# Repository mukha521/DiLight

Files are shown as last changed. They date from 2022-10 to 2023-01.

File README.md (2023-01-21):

# DiLight

### Простой светильник с плавным включением и выключением света с датчиком расстояния vl53l0x от ST на базе STM32G030

[Код main()](/firmware/Core/Src/main.c)

[Драйвер vl53l0x](/firmware/Drivers/vl53l0x/)

При долгом удержании пальца на тач-кнопке, включается режим конфигурирования.
Нужно встать на расстоянии, где светильник будет включаться и тапнуть по кнопке.
Затем встать на расстоянии, где светильник будет отключаться и тапнуть по кнопке.
Конфигурация хранится на последней странице флеш-памяти контроллера.

Светильник включается если человек (или что-то другое) приближается на растояние, установленное при конфигурировании и выключается как только человек удаляется на расстояние большее, чем рысстояние выключения.
Тап по кнопке по кругу переключает ражимы работы светильника: Нормальный -> Всегда включен -> Всегда выключен.

[Схема rev.2.0](/kicad/rev.2.0/DiLight_2.0.pdf)

[Интерактивный BOM-лист](/kicad/rev.2.0/bom/)

В устройстве есть защита от переполюсовки птания (подключение с обратной полярностью), но нет защиты от превышения напряжения (12v) и от короткого замыкания по нагрузке. Целью была миниатюризация устройства.

#### Фото реального устройства:

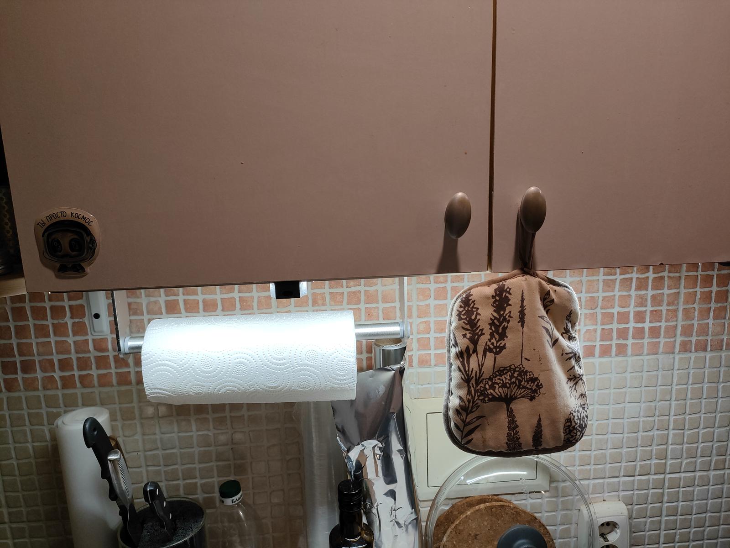
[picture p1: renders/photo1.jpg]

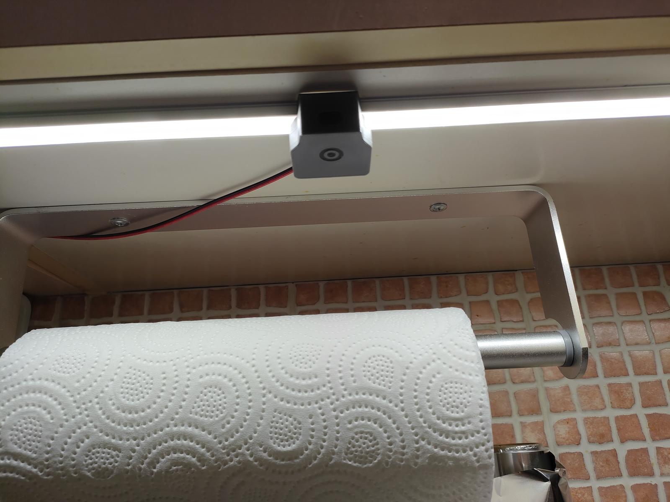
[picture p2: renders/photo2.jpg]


#### Видео с демонстрацией работы:

(кликнуть по изображению - ссылка на YouTube)

YouTube video (http://www.youtube.com/watch?v=1dccDMPywVc)

#### История:

rev.2.0a:
- Исправлена маркировка +/- для терминала LEDs

rev.2.0:
- Уменьшен размер платы
- Использован менее мощный MOSFET в корпусе SOT-23
- Убраны ограничивающие резисторы с разъемов
- Убрана разводка UART на разъем программирования
- Только один терминал для подключения ленты
- Плата с корпусом теперь надевается на профиль для ленты. Не нужно разрезать профиль.

rev.1.1
- винтовой терминал вместо "бочко-разъема" для шнура питания
- MOSFET вместо диода в качестве защиты от обратной полярности питания

#### Рендер платы:
rev.2.0a:
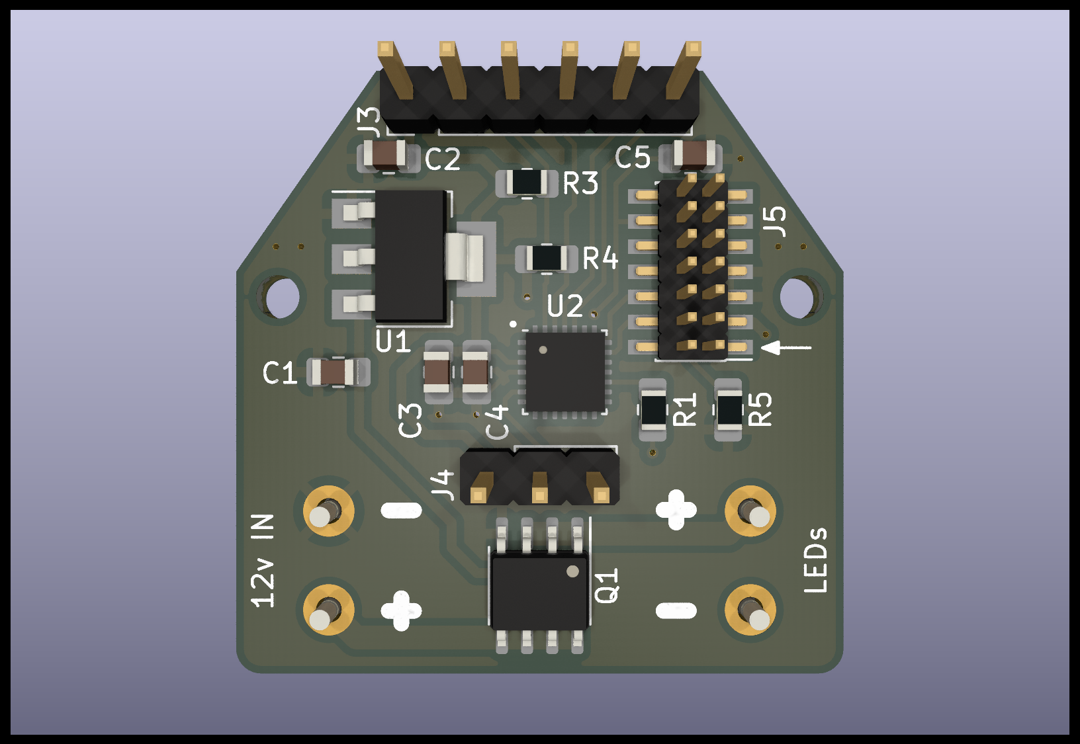
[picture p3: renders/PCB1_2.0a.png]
PCB1 rev.2.0a

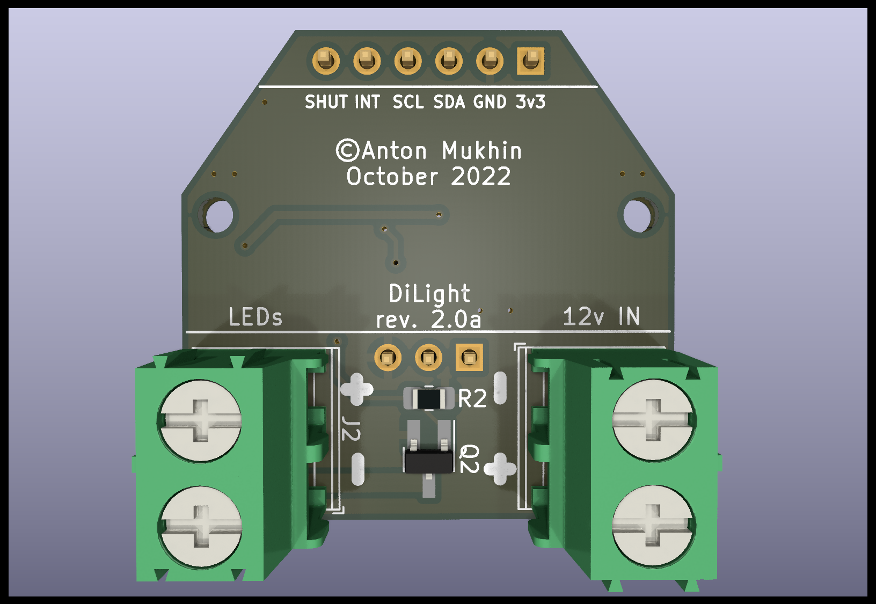
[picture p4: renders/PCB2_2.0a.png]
PCB2 rev.2.0a


rev.2.0:
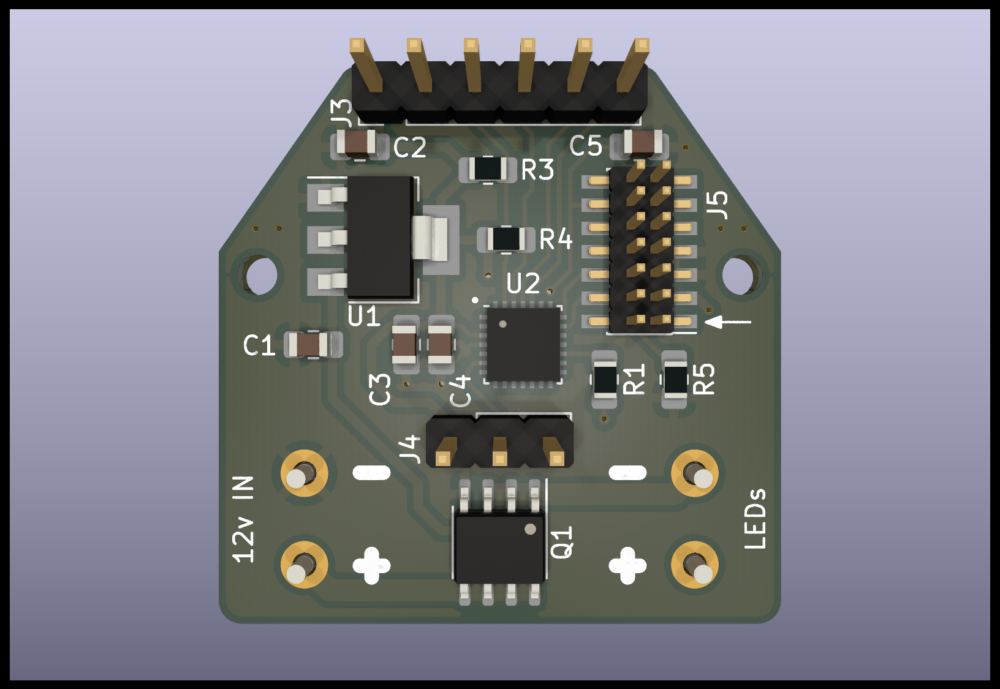
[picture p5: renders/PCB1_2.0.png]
PCB1 rev.2.0

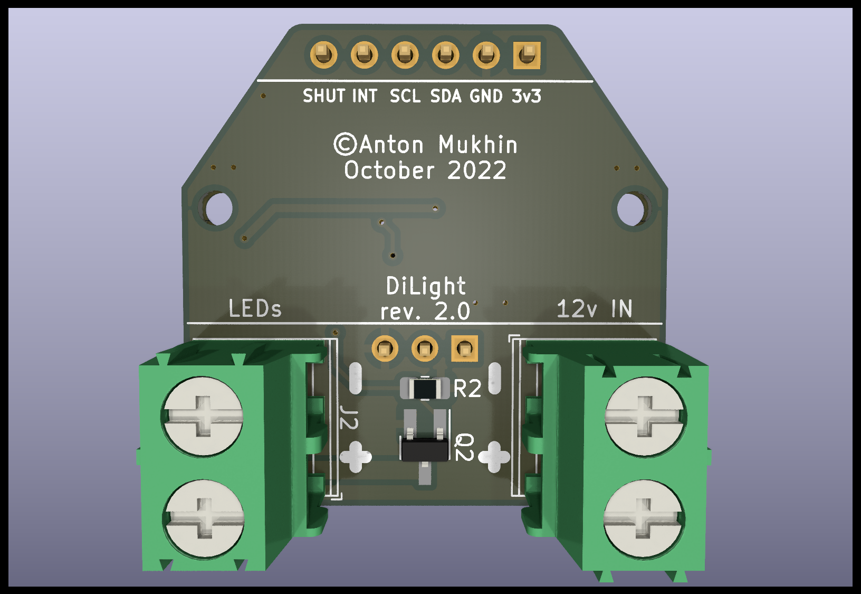
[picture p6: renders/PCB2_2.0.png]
PCB2 rev.2.0


rev.1.1:
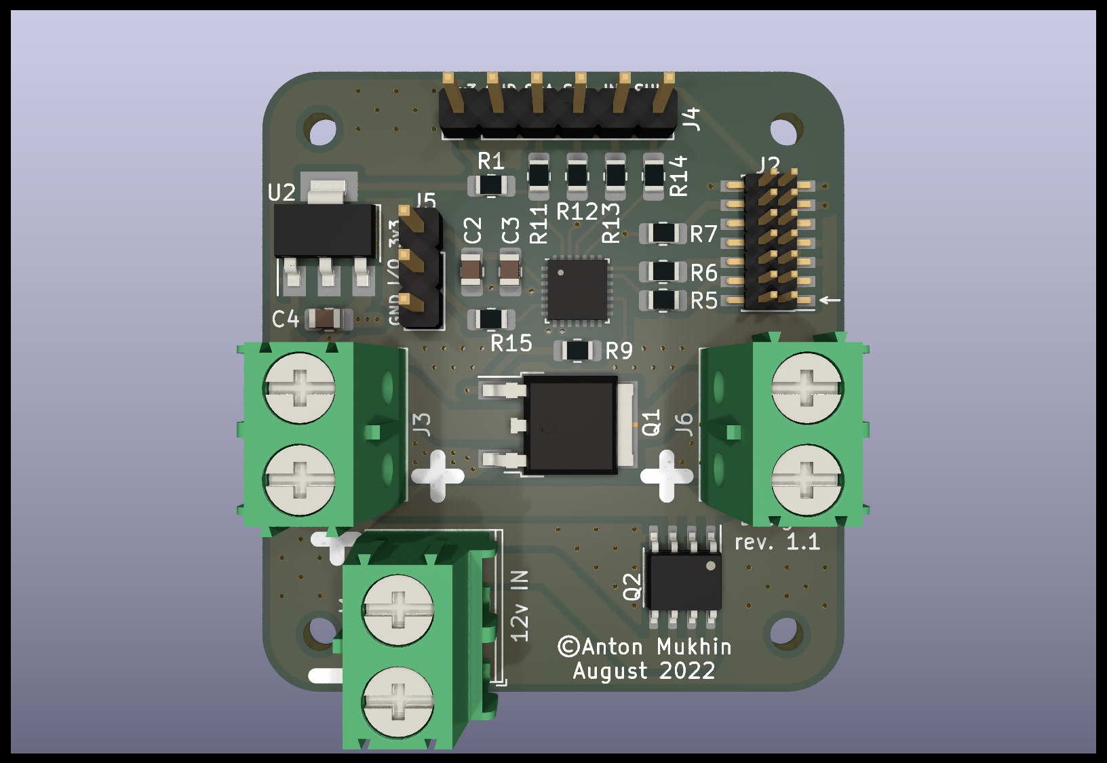
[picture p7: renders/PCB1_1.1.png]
PCB1 rev.1.1

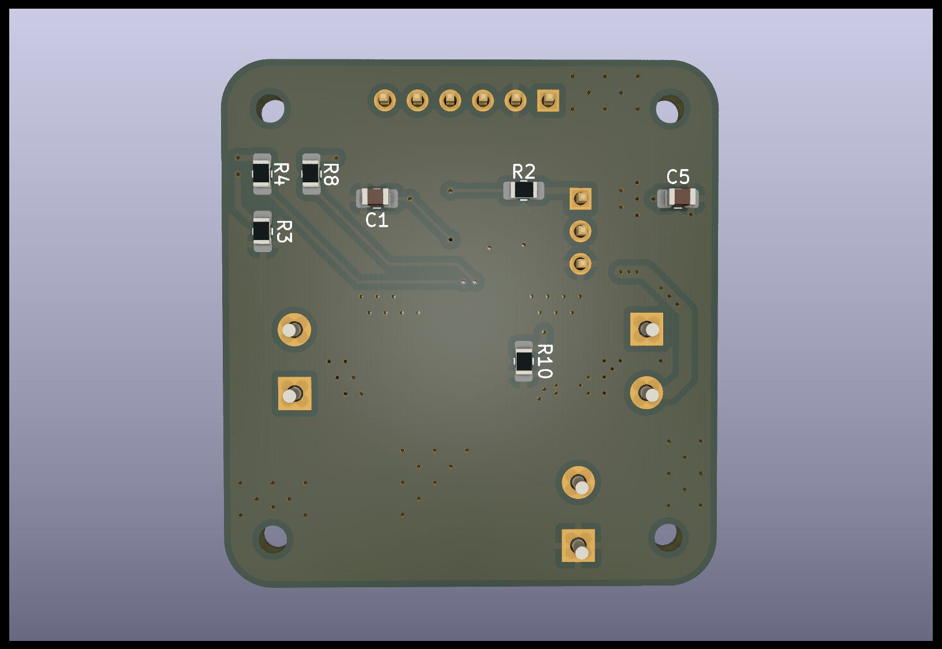
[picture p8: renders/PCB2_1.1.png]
PCB2 rev.1.1


#### Рендер устройства:
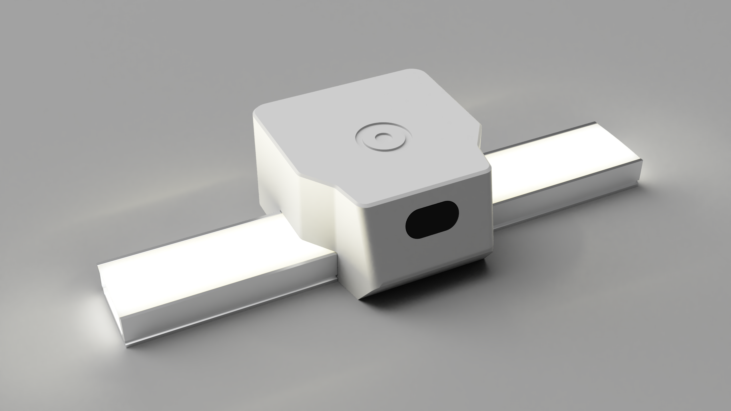
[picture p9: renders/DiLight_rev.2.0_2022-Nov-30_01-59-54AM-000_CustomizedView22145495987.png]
render1

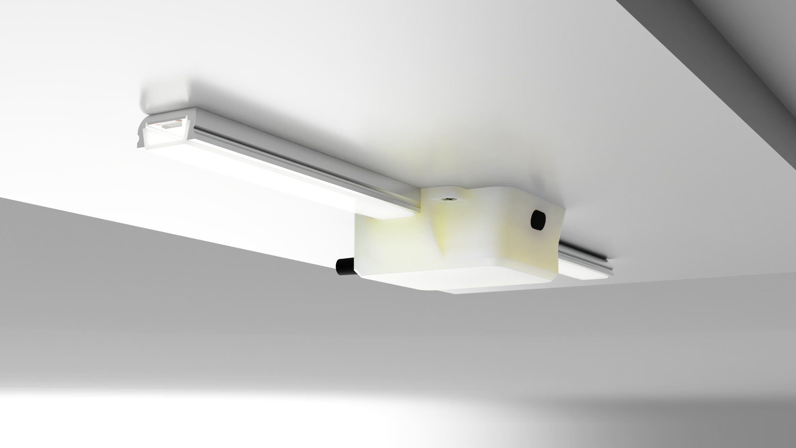
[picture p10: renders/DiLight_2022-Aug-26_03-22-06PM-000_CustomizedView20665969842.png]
render2

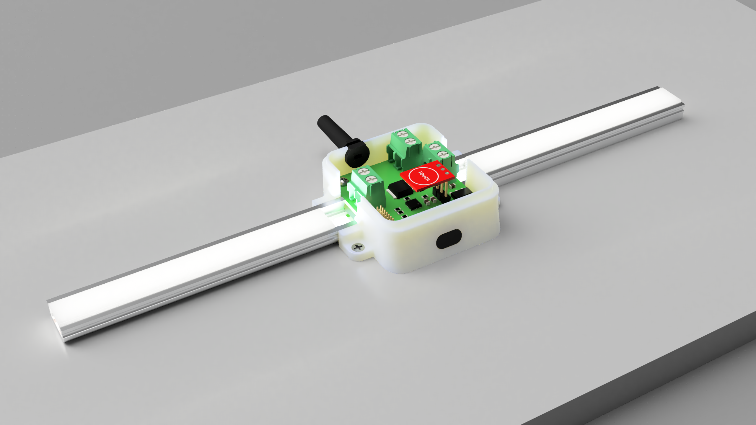
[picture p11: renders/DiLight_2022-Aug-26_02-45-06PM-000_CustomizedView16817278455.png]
render3

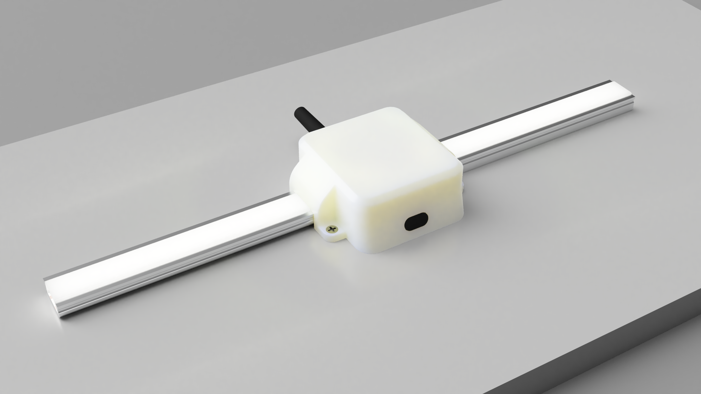
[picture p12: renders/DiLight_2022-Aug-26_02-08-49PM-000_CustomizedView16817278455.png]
render4


#### Промежуточные фото платы (флюс не отмыт :) )
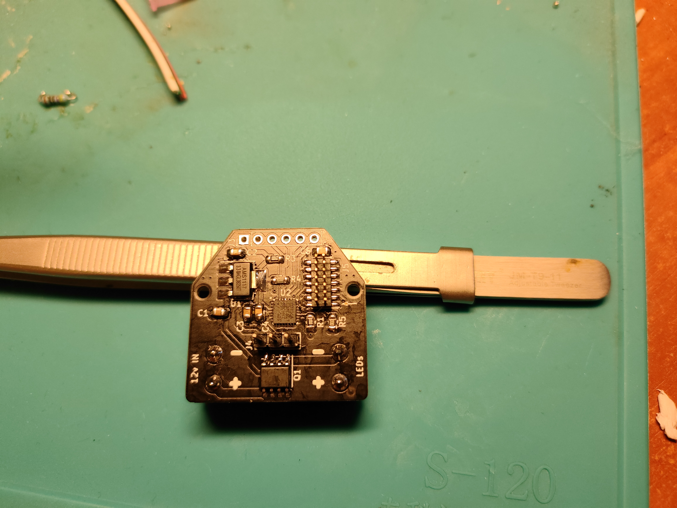
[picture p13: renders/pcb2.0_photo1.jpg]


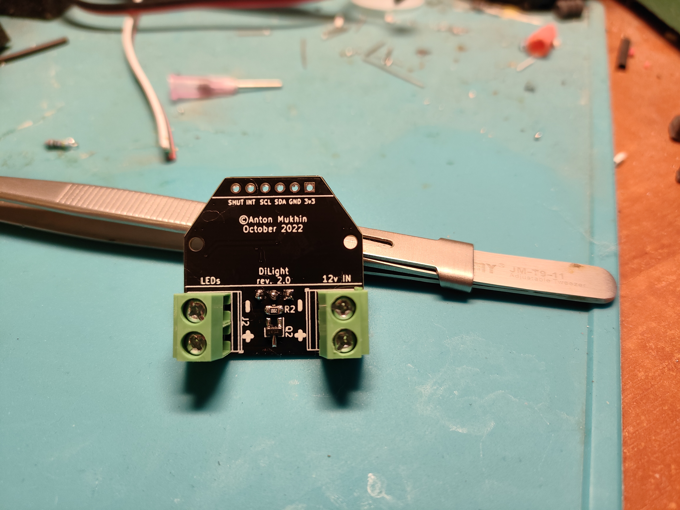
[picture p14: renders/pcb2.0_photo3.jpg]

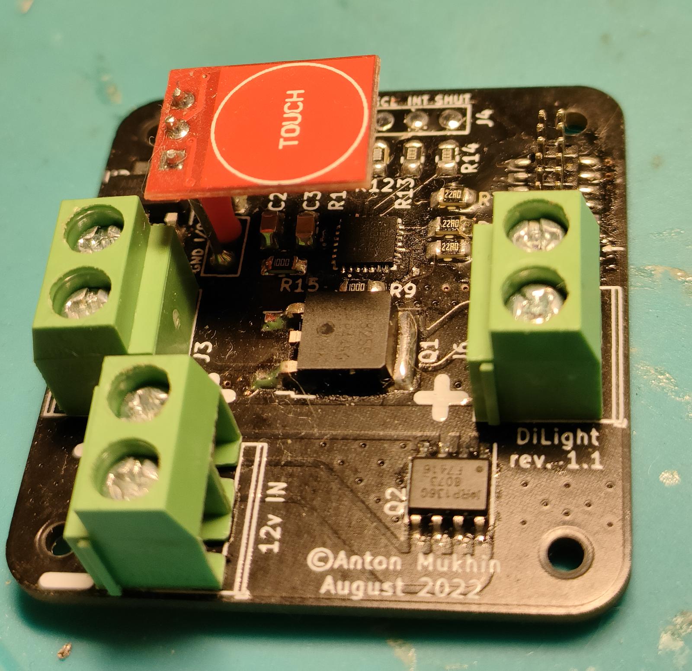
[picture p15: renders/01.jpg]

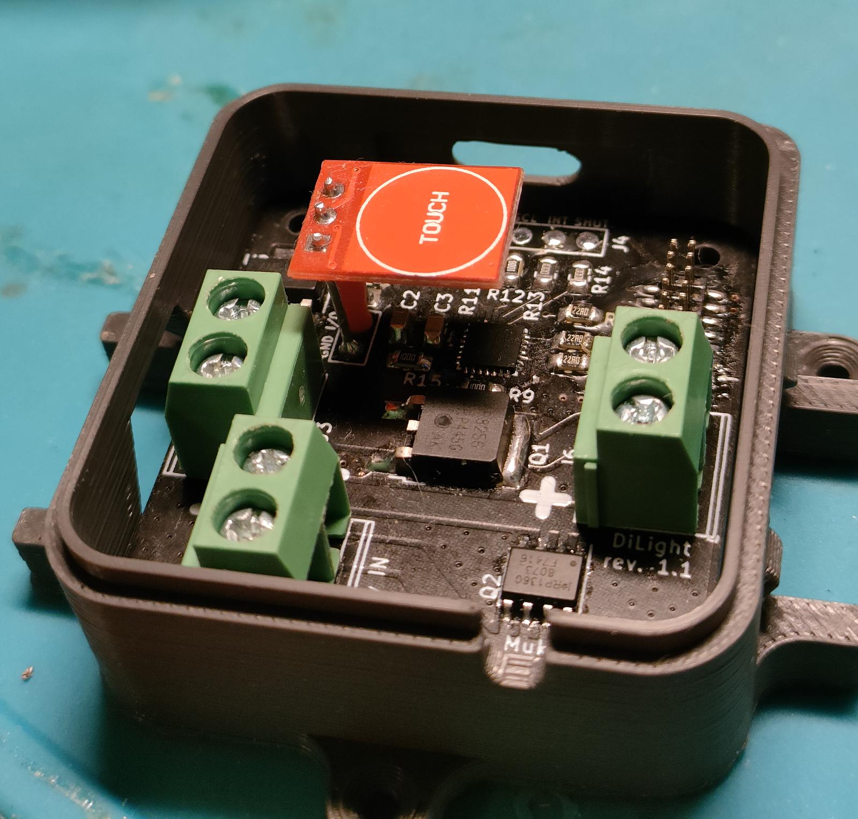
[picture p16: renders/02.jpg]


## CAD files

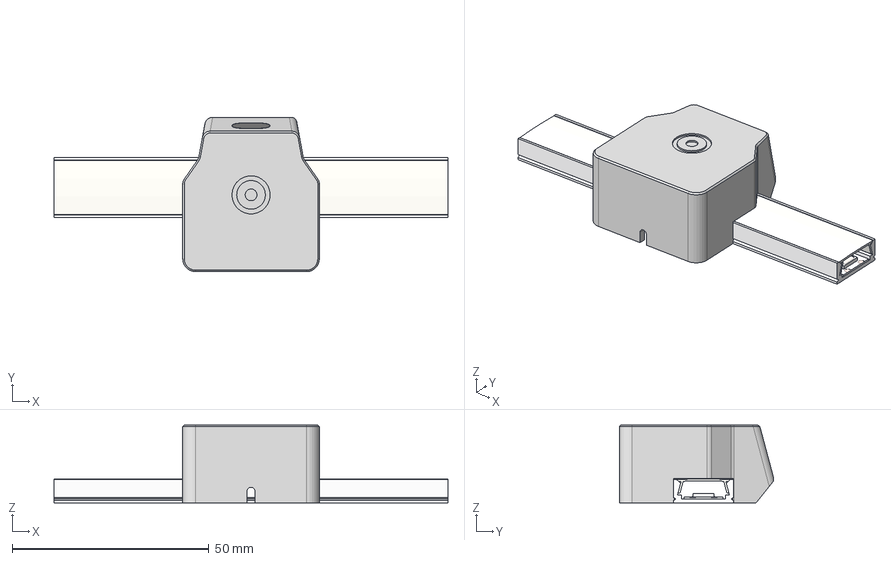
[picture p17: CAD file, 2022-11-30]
STEP/DiLight rev.2.0.step
100.0 x 39.2 x 19.8 mm
strip x 4
LED SMD5054 x 12
resistor x 4
DiLight_2.0 PCB
ScrewTerminalCover x 2
Pin x 4
pan head cross recess screw_iso_ISO 7045 - M2 x 3 - Z - 3N x 4
PCB
Lens
Components
touch button TTP223
M2.2 x 6.5 Rounded Head Screw x 2

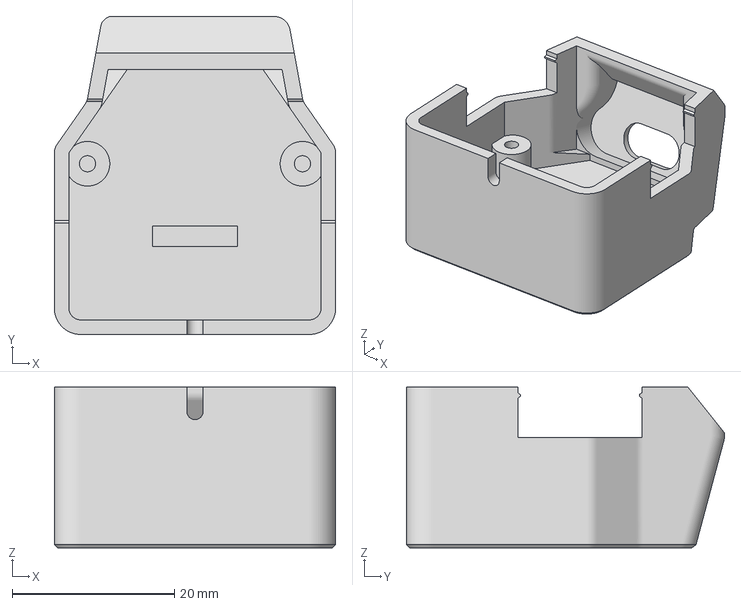
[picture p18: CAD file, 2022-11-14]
STL/Box.3mf
34.7 x 39.2 x 19.8 mm

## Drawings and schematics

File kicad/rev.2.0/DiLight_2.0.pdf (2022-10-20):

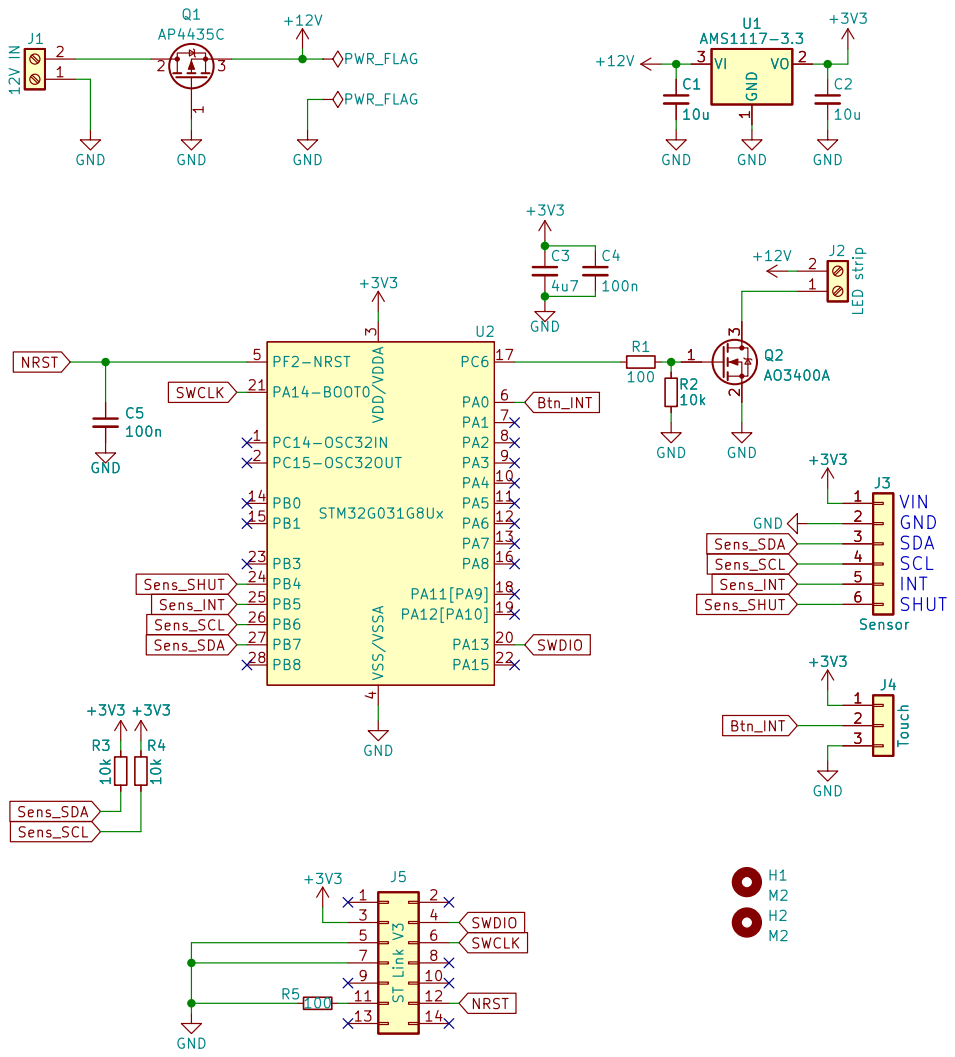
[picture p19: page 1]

File: DiLight_2.0.kicad_sch Sheet: / Anton Mukhin

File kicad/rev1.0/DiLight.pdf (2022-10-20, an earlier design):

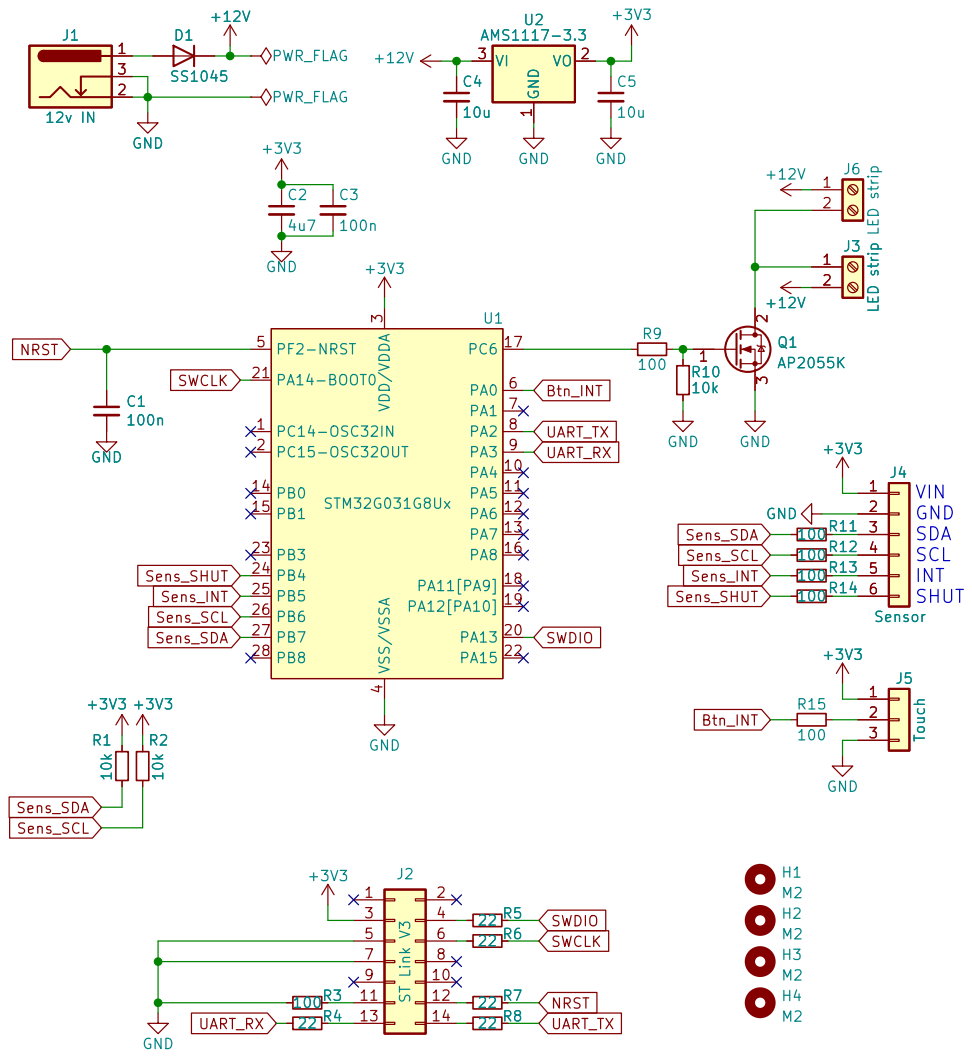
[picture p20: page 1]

File: DiLight.kicad_sch Sheet: / Anton Mukhin

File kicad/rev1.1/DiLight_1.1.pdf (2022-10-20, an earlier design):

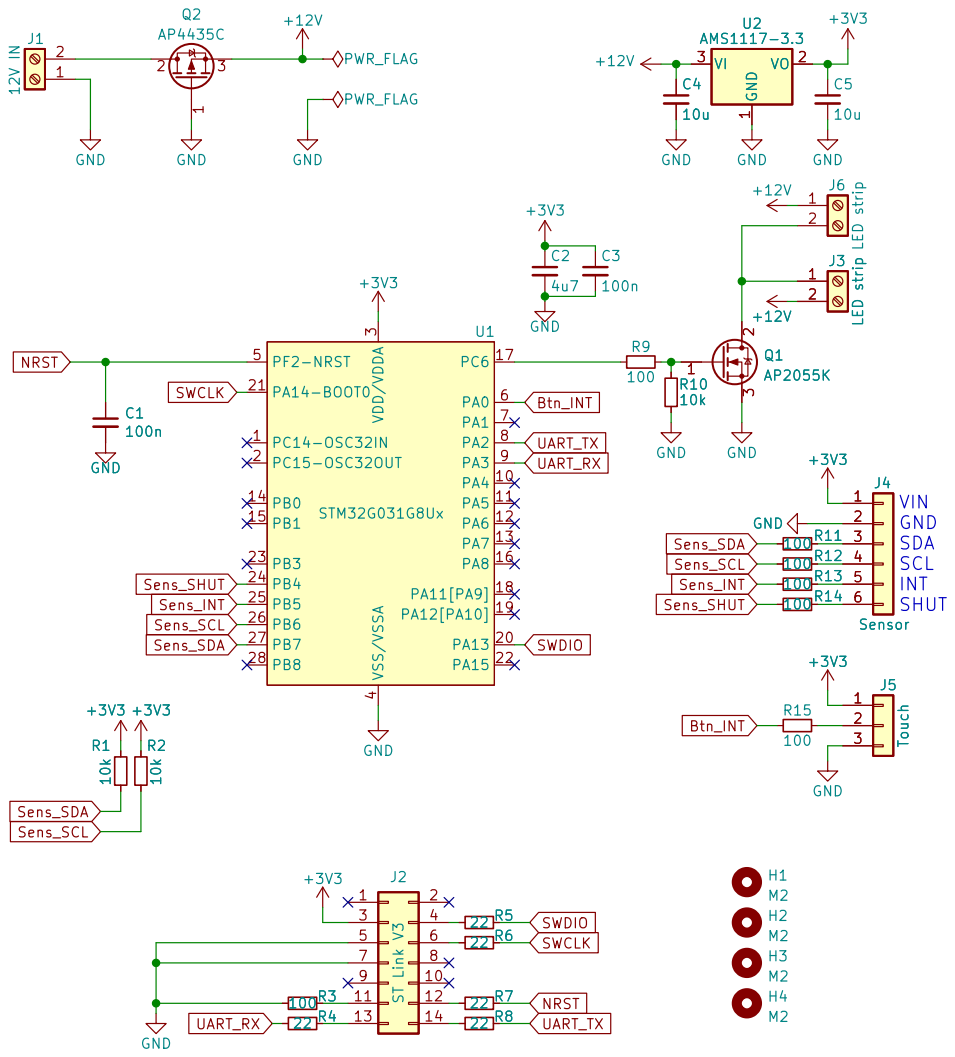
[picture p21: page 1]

File: DiLight_1.1.kicad_sch Sheet: / Anton Mukhin

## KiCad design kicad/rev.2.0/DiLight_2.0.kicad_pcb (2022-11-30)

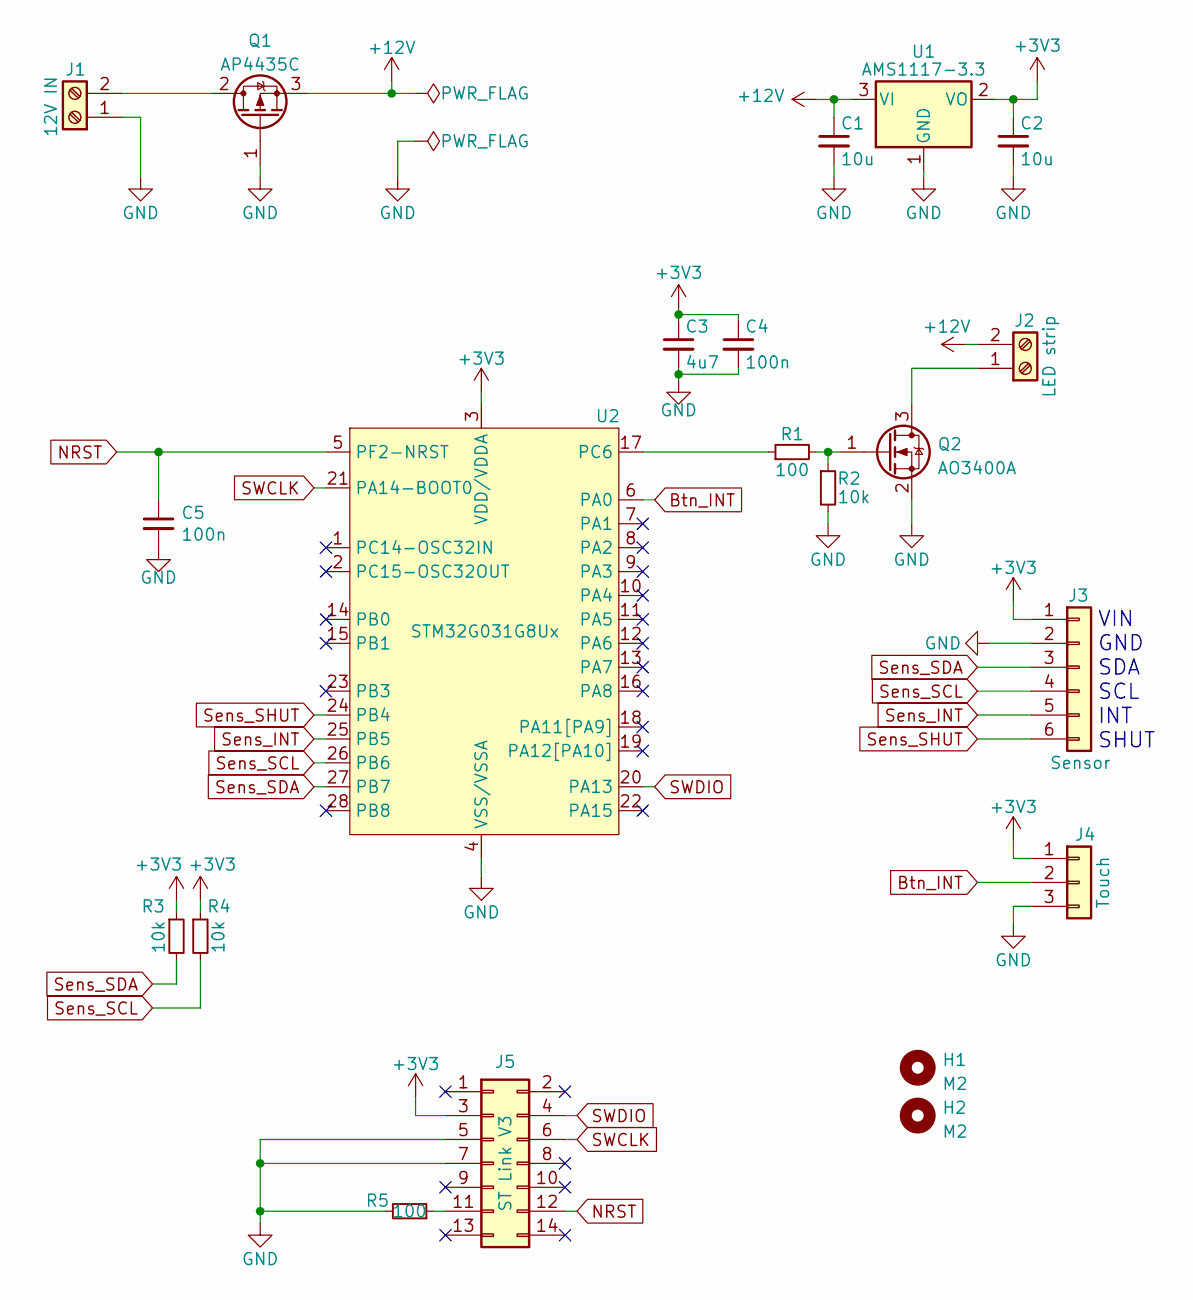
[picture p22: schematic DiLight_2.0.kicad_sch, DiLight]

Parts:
C1, C2: 10u; C_0805_2012Metric_Pad1.18x1.45mm_HandSolder
C3: 4u7; C_0805_2012Metric_Pad1.18x1.45mm_HandSolder
C4, C5: 100n; C_0805_2012Metric_Pad1.18x1.45mm_HandSolder
H1, H2: M2; MountingHole_2.2mm_M2_DIN965
J1: 12V IN; TerminalBlock_Phoenix_PT-1,5-2-5.0-H_1x02_P5.00mm_Horizontal
J2: LED strip; TerminalBlock_Phoenix_PT-1,5-2-5.0-H_1x02_P5.00mm_Horizontal
J3: Sensor; PinHeader_1x06_P2.54mm_Vertical
J4: Touch; PinHeader_1x03_P2.54mm_Vertical
J5: ST Link V3; PinHeader_2x07_P1.27mm_Vertical_SMD
Q1: AP4435C; SOP-8_PMOS_GDS
Q2: AO3400A; SOT-23_Handsoldering
R1, R5: 100; R_0805_2012Metric_Pad1.20x1.40mm_HandSolder
R2, R3, R4: 10k; R_0805_2012Metric_Pad1.20x1.40mm_HandSolder
U1: AMS1117-3.3; SOT-223-3_TabPin2
U2: STM32G031G8Ux; QFN-28_4x4mm_P0.5mm

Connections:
+3V3: C2.1, C3.1, C4.1, J3.1, J4.1, J5.3, R3.1, R4.1, U1.2 (VO), U2.3 (VDD/VDDA)
+12V: C1.1, J2.2, Q1.3 (S), U1.3 (VI)
Btn_INT: J4.2, U2.6 (PA0)
GND: C1.2, C2.2, C3.2, C4.2, C5.2, J1.1, J3.2, J4.3, J5.5, J5.7, Q1.1 (G), Q2.2 (S), R2.2, R5.2, U1.1 (GND), U2.4 (VSS/VSSA)
NRST: C5.1, J5.12, U2.5 (PF2-NRST)
unnamed: J1.2, Q1.2 (D)
unnamed: J2.1, Q2.3 (D)
unnamed: J5.11, R5.1
unnamed: Q2.1 (G), R1.2, R2.1
unnamed: R1.1, U2.17 (PC6)
SWCLK: J5.6, U2.21 (PA14-BOOT0)
SWDIO: J5.4, U2.20 (PA13)
Sens_INT: J3.5, U2.25 (PB5)
Sens_SCL: J3.4, R4.2, U2.26 (PB6)
Sens_SDA: J3.3, R3.2, U2.27 (PB7)
Sens_SHUT: J3.6, U2.24 (PB4)

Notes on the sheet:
VIN GND SDA SCL INT SHUT

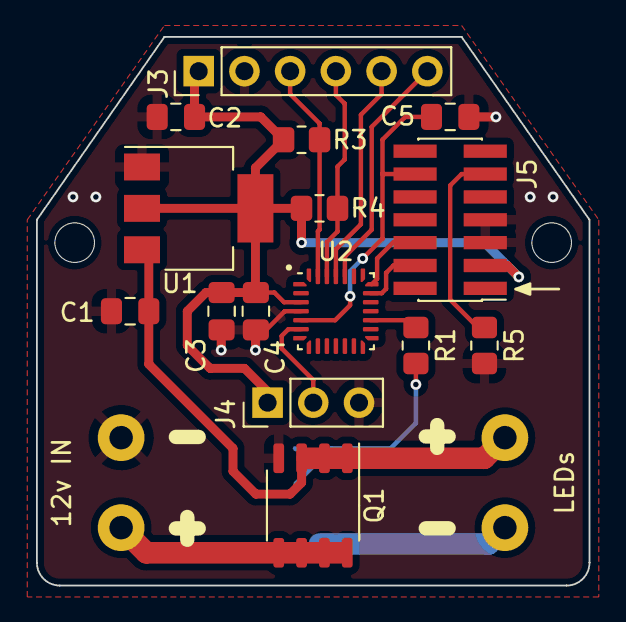
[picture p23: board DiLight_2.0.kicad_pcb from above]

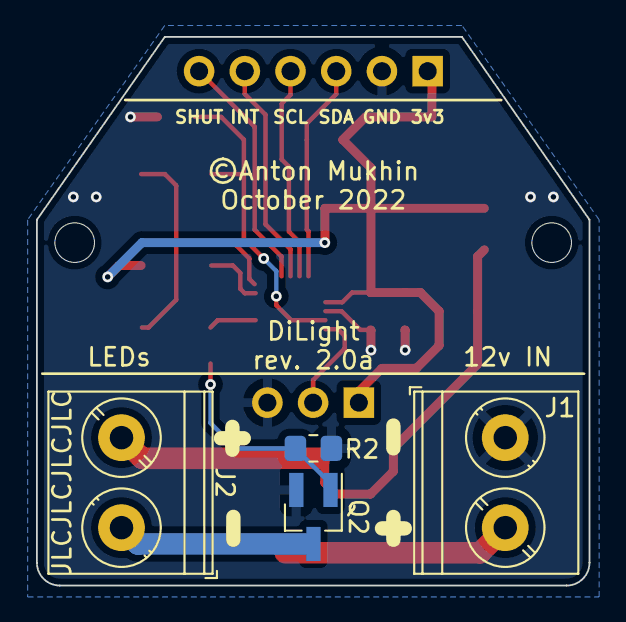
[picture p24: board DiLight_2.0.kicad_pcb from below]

Board: 2 copper layers, 30.7 x 30.5 mm, 21 parts (4 on the bottom side), 16 nets.

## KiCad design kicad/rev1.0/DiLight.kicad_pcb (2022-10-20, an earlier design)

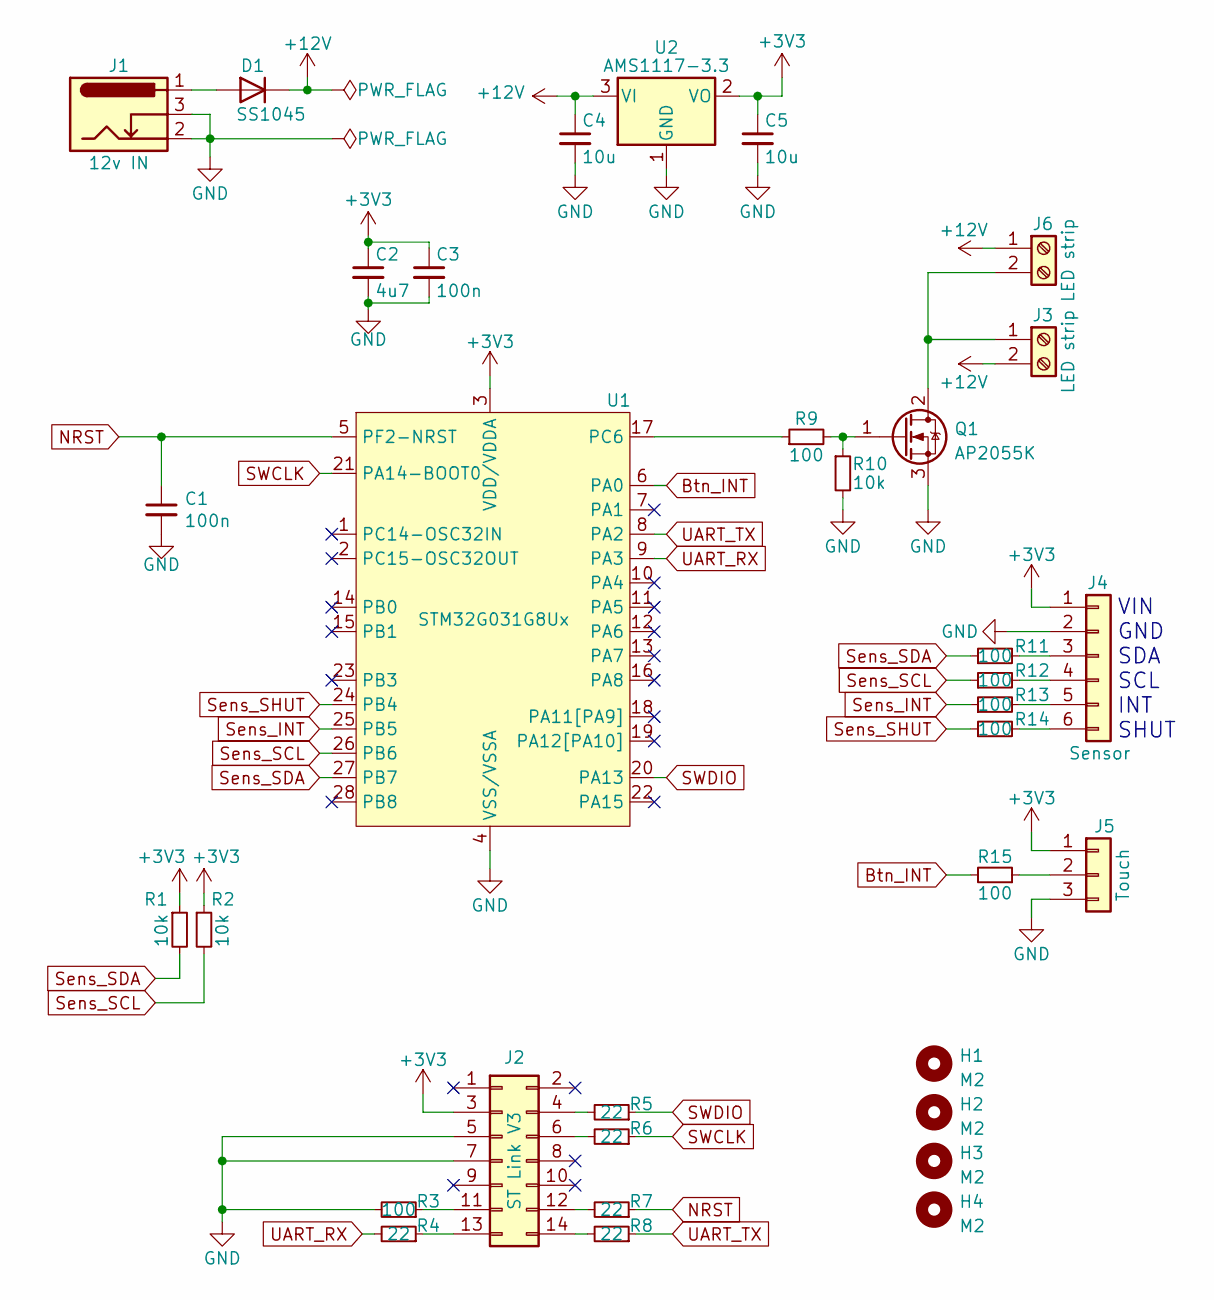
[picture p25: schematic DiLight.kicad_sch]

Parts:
C1, C3: 100n; C_0805_2012Metric_Pad1.18x1.45mm_HandSolder
C2: 4u7; C_0805_2012Metric_Pad1.18x1.45mm_HandSolder
C4, C5: 10u; C_0805_2012Metric_Pad1.18x1.45mm_HandSolder
D1: SS1045; D_SMB-SMC_Universal_Handsoldering
H1, H2, H3, H4: M2; MountingHole_2.2mm_M2_DIN965
J1: 12v IN; BarrelJack_Horizontal
J2: ST Link V3; PinHeader_2x07_P1.27mm_Vertical_SMD
J3, J6: LED strip; TerminalBlock_Phoenix_PT-1,5-2-5.0-H_1x02_P5.00mm_Horizontal
J4: Sensor; PinHeader_1x06_P2.54mm_Vertical
J5: Touch; PinHeader_1x03_P2.54mm_Vertical
Q1: AP2055K; TO-252-2
R1, R2, R10: 10k; R_0805_2012Metric_Pad1.20x1.40mm_HandSolder
R3, R9, R11, R12, R13, R14, R15: 100; R_0805_2012Metric_Pad1.20x1.40mm_HandSolder
R4, R5, R6, R7, R8: 22; R_0805_2012Metric_Pad1.20x1.40mm_HandSolder
U1: STM32G031G8Ux; QFN-28_4x4mm_P0.5mm
U2: AMS1117-3.3; SOT-223-3_TabPin2

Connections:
+3V3: C2.1, C3.1, C5.1, J2.3, J4.1, J5.1, R1.1, R2.1, U1.3 (VDD/VDDA), U2.2 (VO)
+12V: C4.1, D1.1 (K), J3.2, J6.1, U2.3 (VI)
Btn_INT: R15.2, U1.6 (PA0)
GND: C1.2, C2.2, C3.2, C4.2, C5.2, J1.2, J1.3, J2.5, J2.7, J4.2, J5.3, Q1.3 (S), R3.2, R10.2, U1.4 (VSS/VSSA), U2.1 (GND)
NRST: C1.1, R7.1, U1.5 (PF2-NRST)
unnamed: D1.2 (A), J1.1
unnamed: J2.4, R5.2
unnamed: J2.6, R6.2
unnamed: J2.11, R3.1
unnamed: J2.12, R7.2
unnamed: J2.13, R4.1
unnamed: J2.14, R8.2
unnamed: J5.2, R15.1
unnamed: J3.1, J6.2, Q1.2 (D)
unnamed: R9.1, U1.17 (PC6)
unnamed: Q1.1 (G), R9.2, R10.1
unnamed: J4.3, R11.2
unnamed: J4.4, R12.2
unnamed: J4.5, R13.2
unnamed: J4.6, R14.2
SWCLK: R6.1, U1.21 (PA14-BOOT0)
SWDIO: R5.1, U1.20 (PA13)
Sens_INT: R13.1, U1.25 (PB5)
Sens_SCL: R2.2, R12.1, U1.26 (PB6)
Sens_SDA: R1.2, R11.1, U1.27 (PB7)
Sens_SHUT: R14.1, U1.24 (PB4)
UART_RX: R4.2, U1.9 (PA3)
UART_TX: R8.1, U1.8 (PA2)

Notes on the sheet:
VIN GND SDA SCL INT SHUT

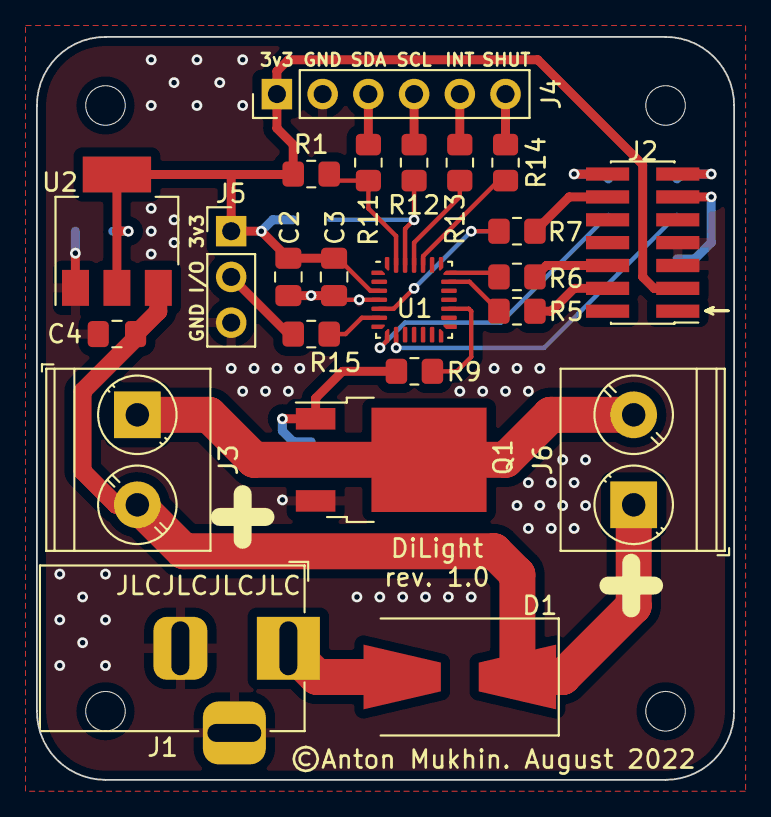
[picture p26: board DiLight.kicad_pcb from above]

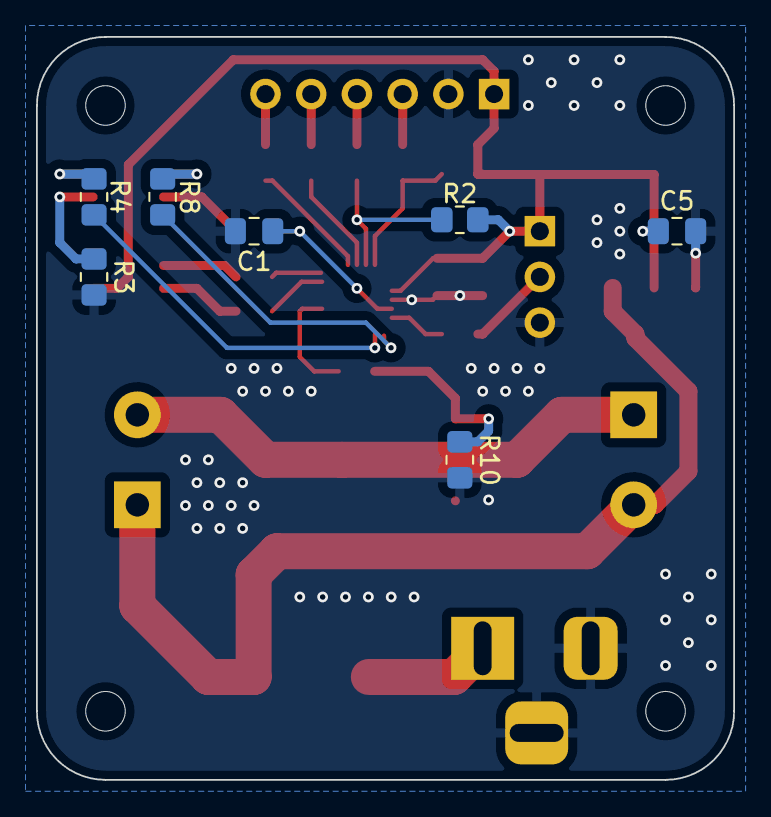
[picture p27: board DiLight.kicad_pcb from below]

Board: 2 copper layers, 38.7 x 41.3 mm, 34 parts (7 on the bottom side), 28 nets.

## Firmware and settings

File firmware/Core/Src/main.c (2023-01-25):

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
/* Includes ------------------------------------------------------------------*/
#include "main.h"

/* USER CODE BEGIN Includes */
#include "string.h"
#include "stdio.h"
#include "VL53L0X.h"
/* USER CODE END Includes */

/* USER CODE BEGIN PTD */

//Configuration structure to keep in last (31) page of FLASH
typedef struct {
	uint32_t token;			//CONF_TOKEN
	uint16_t dist_on;		//distance to turn on lights
	uint16_t dist_off;	//distance to turn off lights
} conf_t;
struct FLASH_sector {
	uint8_t  data[8];		//Config data
	uint32_t counter;		//Configuration write counter
	uint32_t checksum;	//Checksum to verify saved data
};

typedef enum DLMode_t_enum {
	DL_normal = 0,
	DL_manual_on,
	DL_manual_off,
	DL_need_config,
	DL_config_waiting,
	DL_config_accepted,
	DL_error
} DLMode_t;

/* USER CODE END PTD */

/* USER CODE BEGIN PD */

#define DEFAULT_DIST_ON		500											//Default lights on distance
#define DEFAULT_DIST_OFF	1000										//Default lights off distance
#define MIN_DIST_GAP			100											//Min gap between on and off distances
#define MAX_DIST					1400										//Max distance that could be reliably measured by the sensor

#define CONF_TOKEN				0x000A0200							//32bit token to check the configuration struct in the FLASH (000A - DiLight; rev2.0)
#define CONF_FLASH_ADDR 	((uint32_t)0x0800F800)	//FLASH address of the page to save configuration to
#define CONF_FLASH_PAGE 	31											//FLASH page number (from 0 to PgCount-1)

/* USER CODE END PD */

CRC_HandleTypeDef hcrc;

I2C_HandleTypeDef hi2c1;

TIM_HandleTypeDef htim3;
TIM_HandleTypeDef htim16;
TIM_HandleTypeDef htim17;

/* USER CODE BEGIN PV */

//volatile const uint8_t config_flash[1024 * 2] __attribute__((__section__(".conf_data")));

union FLASH_conf {
	  conf_t config;
	  struct FLASH_sector sector;
	  uint32_t data32[4];
	  uint64_t data64[2];
} configuration;
#define FLASH_CONF_SIZE 16

uint8_t  TOF_Ready = 0;							// Flag to ignore TOF IRQ before it is initialized
uint8_t  curLightLevel = 0;					// Current light level (0-99)
uint16_t curDist = 0;								// Current measured distance in mm
uint16_t btn_ticks;									// How many ticks the button is pressed (1 tick = 100ms)
int8_t   dLevel = 1;								// Direction of fade: -1 for fade out; 1 for fade in;
DLMode_t DLmode = DL_normal;				// Global mode: DL_normal, DL_manual_on, DL_manual_off, DL_need_config, DL_config_waiting, DL_config_accepted, DL_error
DLMode_t prev_mode = DL_normal;			// To hold the mode during temporary mode switches
uint8_t  modeSwitch = 0;						// Flag to switch the mode after the button tap

/* USER CODE END PV */

void SystemClock_Config(void);
static void MX_GPIO_Init(void);
static void MX_I2C1_Init(void);
static void MX_TIM3_Init(void);
static void MX_TIM17_Init(void);
static void MX_CRC_Init(void);
static void MX_TIM16_Init(void);
/* USER CODE BEGIN PFP */

volatile void loadConfig(void);							// Load configuration from the FLASH memory
volatile void saveConfig(void);							// Save configuration to the FLASH memory
volatile void setLightLevel(uint8_t level);	// Set the lights level (brightness) 0 - 99
void fastBlink(uint8_t count);							// Fast blink LEDs `count` times
void configure(void);												// Range configuration procedure (set on and off ranges)


/* USER CODE END PFP */

/* USER CODE BEGIN 0 */

//load configuration from FLASH
volatile void loadConfig(void) {
	uint32_t l_Address = CONF_FLASH_ADDR;
	uint32_t l_Index = 0;

	//Reading from FLASH
	while (l_Address < (CONF_FLASH_ADDR + FLASH_CONF_SIZE)) {
	  configuration.data64[l_Index] = *(__IO uint64_t *)l_Address;
	  l_Index += 1;
	  l_Address += 8;
	}

	//Calculate a hash from the configuration
	if (HAL_CRC_Calculate(&hcrc, configuration.data32, 2) != configuration.sector.checksum
			|| configuration.config.token != CONF_TOKEN) {
		//First start or configuration is corrupted
		saveConfig();  //Save dafault config
	} // else successfully read the configuration

}

//save configuration to FLASH
volatile void saveConfig(void) {
  static FLASH_EraseInitTypeDef EraseInitStruct;
  uint32_t l_Address = CONF_FLASH_ADDR;
  uint32_t l_Index = 0;
  uint32_t l_Error = 0;

  //We need it to erase a page
  EraseInitStruct.TypeErase = FLASH_TYPEERASE_PAGES;
  EraseInitStruct.Page      = CONF_FLASH_PAGE;
  EraseInitStruct.NbPages   = 1;

  if (configuration.config.token != CONF_TOKEN) {
	  //first start
	  //Nullify the struct
	  memset(configuration.data64, 0, sizeof(configuration.data64));
	  //set default values
	  configuration.config.token = CONF_TOKEN;
	  configuration.config.dist_on = DEFAULT_DIST_ON;
	  configuration.config.dist_off = DEFAULT_DIST_OFF;

	  configuration.sector.counter = 0;
  }

  // Check if the distances are good.
  // (1 max distance is respected. 2 min gap between on and off distances is respected)
  if (configuration.config.dist_off > MAX_DIST) configuration.config.dist_off = MAX_DIST;
  if (configuration.config.dist_off < MIN_DIST_GAP) configuration.config.dist_off = MIN_DIST_GAP;
  if (configuration.config.dist_on > configuration.config.dist_off - MIN_DIST_GAP) configuration.config.dist_on = configuration.config.dist_off - MIN_DIST_GAP;
  configuration.sector.counter += 1;
  configuration.sector.checksum = HAL_CRC_Calculate(&hcrc, configuration.data32, 2);

  HAL_FLASH_Unlock();															//Unlock the FLASH
  HAL_FLASHEx_Erase(&EraseInitStruct, &l_Error);	//Erase the page

  // Programming the config

  while (l_Address < (CONF_FLASH_ADDR + FLASH_CONF_SIZE)) {
	  if  (HAL_FLASH_Program(FLASH_TYPEPROGRAM_DOUBLEWORD, l_Address, configuration.data64[l_Index]) == HAL_OK) {
		  l_Index += 1;
		  l_Address += 8;
	  }
  }
  HAL_FLASH_Lock();
  HAL_Delay(50);
}

// Fast blink LEDs `count` times
void fastBlink(uint8_t count) {
	uint8_t i, pll;

	pll = curLightLevel;
	setLightLevel(0);
	for (i = 0; i < count; i++) {
		setLightLevel(99);
		HAL_Delay(80);
		setLightLevel(0);
		HAL_Delay(80);
	}
	setLightLevel(pll);
}

// Range configuration procedure (set on and off ranges)
void configure(void) {
	DLmode = DL_config_waiting;

	//Fast blink 5 times
	fastBlink(5);

	//Configure ON distance
	while (DLmode == DL_config_waiting) {
		HAL_Delay(250);
		if (curDist > MAX_DIST - MIN_DIST_GAP) setLightLevel(0);
		// (x - in_min) * (out_max - out_min) / (in_max - in_min) + out_min
		// (x - 0) * (50 - 0) / (1400 - 0) + 0
		// x * 50 / 1400
		// (99 - curDist * 99 / 2000)     //old version
		else setLightLevel((uint8_t)(50 - curDist * 50 / (MAX_DIST - MIN_DIST_GAP)));		// Map light level to the distance
	}
	configuration.config.dist_on = curDist;			// this will be checked during config save

	//Fast blink 2 times
	DLmode = DL_config_waiting;
	fastBlink(2);

	//Configure OFF distance
	while (DLmode == DL_config_waiting) {
		HAL_Delay(250);
		if (curDist > MAX_DIST) setLightLevel(0);
		else setLightLevel((uint8_t)(50 - curDist * 50 / MAX_DIST));		// Map light level to the distance
	}
	configuration.config.dist_off = curDist;		// this will be checked during config save

  saveConfig();

	//Fast blink 5 times
  fastBlink(5);
}

/* USER CODE END 0 */

/**
  * @brief  The application entry point.
  * @retval int
  */
int main(void)
{
  /* MCU Configuration--------------------------------------------------------*/

  /* Reset of all peripherals, Initializes the Flash interface and the Systick. */
  HAL_Init();

  /* Configure the system clock */
  SystemClock_Config();

  /* Initialize all configured peripherals */
  MX_GPIO_Init();
  MX_I2C1_Init();
  MX_TIM3_Init();
  MX_TIM17_Init();
  MX_CRC_Init();
  MX_TIM16_Init();
  /* USER CODE BEGIN 2 */

  // TIM3  - PWM timer
  // TIM16 - ticks timer (10Hz - 100ms)
  // TIM17 - timer for light fading

  loadConfig();

  // Set IO timeout for range sensor
  setTimeout(250);

  TOF_Ready = initVL53L0X(1);
  if (TOF_Ready) {
		// lower the return signal rate limit (default is 0.25 MCPS)
		// setSignalRateLimit(0.1);
		// increase laser pulse periods (defaults are 14 and 10 PCLKs)
		// setVcselPulsePeriod(VcselPeriodPreRange, 18);
		// setVcselPulsePeriod(VcselPeriodFinalRange, 14);
		setMeasurementTimingBudget( 500 * 1000UL );		// integrate over 500 ms per measurement

		// Start measurements every second
		startContinuous(1000);
  }
  HAL_TIM_PWM_Start(&htim3, TIM_CHANNEL_1);

  // Fast-blink 10 times to indicate range sensor error
	if (!TOF_Ready) {
		fastBlink(10);
	}


  /* USER CODE END 2 */

  /* Infinite loop */
  /* USER CODE BEGIN WHILE */
  while (1)
  {
  	if (DLmode == DL_need_config) {
  		configure();
  		DLmode = prev_mode;
  	}

  	// Check if the button was tapped and we should switch the mode
  	if (modeSwitch) {
  		modeSwitch = 0;
  		switch (DLmode) {
				case DL_normal:
					DLmode = DL_manual_on;
					fastBlink(1);
					dLevel = 2;
					HAL_TIM_Base_Start_IT(&htim17);
					break;
				case DL_manual_on:
					DLmode = DL_manual_off;
					fastBlink(1);
					dLevel = -1;
					HAL_TIM_Base_Start_IT(&htim17);
					break;
				case DL_manual_off:
					DLmode = DL_normal;
					fastBlink(2);
					break;
				default:
					break;
			}
		}

  	HAL_Delay(50);
    /* USER CODE END WHILE */

    /* USER CODE BEGIN 3 */
  }
  /* USER CODE END 3 */
}

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
/* USER CODE BEGIN 4 */

volatile void setLightLevel(uint8_t level) {
	if (level > 99) level = 99;
	curLightLevel = level;

	TIM3->CCR1 = curLightLevel;
}

void HAL_GPIO_EXTI_Rising_Callback(uint16_t GPIO_Pin) {
	// Start counting "ticks" when the sense-button is pressed
	if (GPIO_Pin == Btn_INT_Pin) {
		btn_ticks = 0;
		HAL_TIM_Base_Start_IT(&htim16);
	}
}


void HAL_GPIO_EXTI_Falling_Callback(uint16_t GPIO_Pin) {
	uint16_t dist;

	// Range sensor interrupt (measurement is done)
	if (TOF_Ready && GPIO_Pin == Sens_INT_Pin) {
		dist = readRangeContinuousMillimeters(0);
		if (dist < MAX_DIST)	curDist = dist;
		else curDist = MAX_DIST;
		if (DLmode == DL_normal) {
			if (curDist <= configuration.config.dist_on && curLightLevel < 90) {
				//Turn on the lights
				dLevel = 2;
				HAL_TIM_Base_Start_IT(&htim17);
			}
			if (curDist >= configuration.config.dist_off && curLightLevel == 99) {
				//Turn off the lights
				dLevel = -1;
				HAL_TIM_Base_Start_IT(&htim17);
			}
		}
	}

	// The sense-button is released
	if (GPIO_Pin == Btn_INT_Pin) {
		HAL_TIM_Base_Stop_IT(&htim16);
		if (btn_ticks < 60) {
			// Button was not held for more than 6 seconds
			if (DLmode == DL_config_waiting) {
				DLmode = DL_config_accepted;
			} else {
				modeSwitch = 1;
			}
		}
	}
}

void HAL_TIM_PeriodElapsedCallback(TIM_HandleTypeDef *htim) {
	if(htim->Instance == TIM16) { //check if the interrupt comes from TIM16   // TIM16 - ticks timer (10Hz - 100ms)
		if (btn_ticks < 60) {
			btn_ticks++;
		} else {
			// the button is held for more than 6 seconds
			HAL_TIM_Base_Stop_IT(&htim16);
			prev_mode = DLmode;
			DLmode = DL_need_config;
		}
	}

	// Fade-in / fade-out animation
	if(htim->Instance == TIM17) { //check if the interrupt comes from TIM17  // TIM17 - timer for light fading
		if ((curLightLevel >= 99 && dLevel > 0) || (curLightLevel == 0 && dLevel < 0)) {
			HAL_TIM_Base_Stop_IT(&htim17);
		} else {
			curLightLevel += dLevel;
			setLightLevel(curLightLevel);
		}
	}
}

/* USER CODE END 4 */
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


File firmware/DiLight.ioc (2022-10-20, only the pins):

Mcu.UserName=STM32G031G8Ux
PA0.GPIO_Label=Btn_INT
PA0.Signal=GPXTI0
PA13.Signal=SYS_SWDIO
PA14-BOOT0.Signal=SYS_SWCLK
PB4.GPIO_Label=Sens_SHUT
PB4.Signal=GPIO_Output
PB5.GPIO_Label=Sens_INT
PB5.Signal=GPXTI5
PB6.GPIO_Label=Sens_SCL
PB6.Signal=I2C1_SCL
PB7.GPIO_Label=Sens_SDA
PB7.Signal=I2C1_SDA
PC6.Signal=S_TIM3_CH1

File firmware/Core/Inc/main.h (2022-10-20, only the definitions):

#define Btn_INT_Pin GPIO_PIN_0
#define Btn_INT_GPIO_Port GPIOA
#define Btn_INT_EXTI_IRQn EXTI0_1_IRQn
#define Sens_SHUT_Pin GPIO_PIN_4
#define Sens_SHUT_GPIO_Port GPIOB
#define Sens_INT_Pin GPIO_PIN_5
#define Sens_INT_GPIO_Port GPIOB
#define Sens_INT_EXTI_IRQn EXTI4_15_IRQn
#define Sens_SCL_Pin GPIO_PIN_6
#define Sens_SCL_GPIO_Port GPIOB
#define Sens_SDA_Pin GPIO_PIN_7
#define Sens_SDA_GPIO_Port GPIOB

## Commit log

2022-11-14 tabspace fix. minor changes.
    [Box.3mf]
2022-11-23 PCB silkscreen +/- marks positions fixed. Manual on/off still works if the range sensor is not initialized
    [DiLight_2.0.kicad_pcb]
2022-11-30 kicad backups removed
2022-11-30 more kicad backups removed
2022-11-30 BOM status changed for some components. iBOM regenerated
    [DiLight_2.0.kicad_pcb, DiLight_2.0.kicad_sch]
2022-11-30 New rev.2.0a PCB renders
2022-11-30 Generated new gerbers for rev.2.0a
    [DiLight_2.0-B_Cu.gbl, DiLight_2.0-B_Mask.gbs, DiLight_2.0-B_Paste.gbp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]
2022-11-30 new device render
2022-11-30 Assembly STEP file added
    [DiLight rev.2.0.step]
2023-01-20 Reworked light modes; now there are 3 modes cycled by a button taps - normal, manual on, manual off.
    [main.c]
2023-01-21 Moved modeswitch logic out of the ISR handler; Fixed fade in/out logic so it wont turn on the light when asked to fade out;
    [main.c]

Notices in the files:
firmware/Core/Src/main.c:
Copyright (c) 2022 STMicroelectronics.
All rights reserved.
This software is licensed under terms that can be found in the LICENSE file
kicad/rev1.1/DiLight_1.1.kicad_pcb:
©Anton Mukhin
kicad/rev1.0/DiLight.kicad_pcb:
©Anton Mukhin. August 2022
